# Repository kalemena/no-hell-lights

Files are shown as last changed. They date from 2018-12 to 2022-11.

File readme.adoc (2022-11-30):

= no-hell-lights

*"No Hell"* pronounces like *"Noël"* in French, meaning *"Christmas"* lights.

While this project looks focused on interacting with LED lights, this repository is also a fun way to touch on the below technology:

- Electronic (with very little soldering)
- Arduino IDE coding (C-like) using ESP8266 supporting Wifi
- REST API Designs
- Web-sockets programming
- Web UI - TBD: VueJS UI ?
- Open CV for a little of Machine Learning tools - TBD
- Android - TBD

In short, this repository demonstrate all above topics are "no hell".

== Led Strips

=== Material

* WS2812b comes in 5v or 12v.

[WARNING]
====
12v are hooked 3 by 3, which means that programmatically there are 3 times less leds.
====

Each led consumes 0.2W max, to be safe count 20W for 60 led, that is 20W per meter.

I use 5v 150W power supply so that 10m 600 led strip is fine.

* WS2815 is enhancement of WS2812b (12v with individual address, and with sustain led failure)

* SK6812 is 5v, and has a 4th channel for white light, available in cold or warm white

==== Wiring

Using Arduino Pro Mini 5v as reference.

Wiring for ESP8266 or ESP32 is same as stated below.

As stated in NeoPixel library:

[IMPORTANT]
====
To reduce NeoPixel burnout risk, add 1000 uF capacitor across
pixel power leads, add 300 - 500 Ohm resistor on first pixel's data input
and minimize distance between Arduino and first pixel.  Avoid connecting
on a live circuit...if you must, connect GND first.
====

Then just hook up data pin to one of the pin of arduino.

[NOTE]
====
For 12v strips, make sure not to burn the arduino 5v: don't hook the Vcc !
====

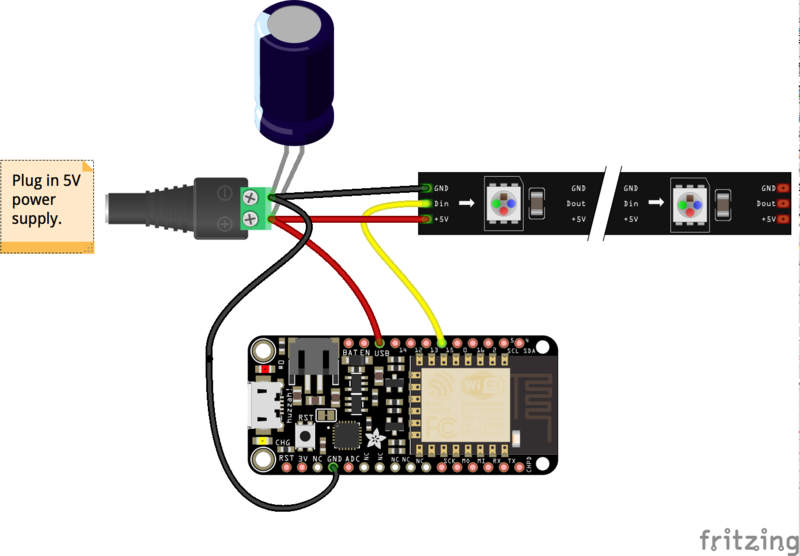
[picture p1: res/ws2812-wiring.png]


=== Board

Details of board can be found under link:boards[]

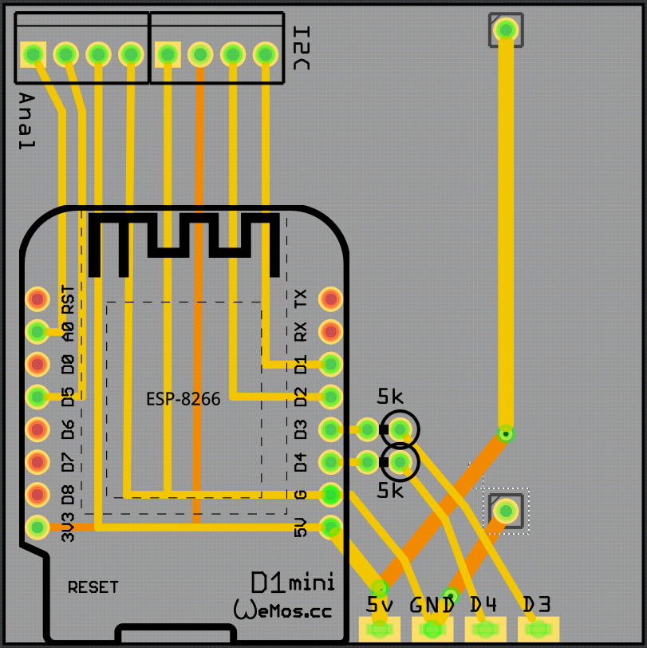
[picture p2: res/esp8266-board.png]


=== Sketches

External samples:

* https://github.com/FastLED/FastLED/blob/master/examples/DemoReel100/DemoReel100.ino[Very Good example]

Internal samples:

* link:sketches/arduino/WS2812/Fast-LED-sample1/Fast-LED-sample1.ino[Fast-LED-sample1.ino]

=== APIs

==== Status

[source,bash]
----
$ curl --request GET http://192.168.1.50/status

{
 "system": {
   "heap": 36944,
   "boot-version": 5,
   "cpu-frequency": 160,
   "sdk": "1.5.3(aec24ac9)",
   "chip-id": 2918146,
   "flash-id": 1458400,
   "flash-size": 4194304,
   "vcc": 65535,
   "gpio": 86053
  },
 "message": "status",
 "properties": {
   "power": 1,
   "animation-mode": "single",
   "brightness": 255,
   "autoplay-duration": 10
  },
 "effects": [
   { "id": 0, "name": "RGB Loop" },
   { "id": 1, "name": "Juggle" },
   { "id": 2, "name": "BPM" },
   { "id": 3, "name": "Sinelon" },
   { "id": 4, "name": "Bouncing Balls" },
   { "id": 5, "name": "Bouncing Balls Multiple" },
   { "id": 6, "name": "Candle" },
   { "id": 7, "name": "Fade-in Fade-out" },
   { "id": 8, "name": "Strobe" },
   { "id": 9, "name": "Halloween Eyes" },
   { "id": 10, "name": "Cylon Bounce" },
   { "id": 11, "name": "New KITT" },
   { "id": 12, "name": "Twinkle" },
   { "id": 13, "name": "Twinkle Random" },
   { "id": 14, "name": "Sparkle" },
   { "id": 15, "name": "Sparkle Snow" },
   { "id": 16, "name": "Running Lights" },
   { "id": 17, "name": "Color Wipe" },
   { "id": 18, "name": "Rainbow Cycle" },
   { "id": 19, "name": "Theater Chase" },
   { "id": 20, "name": "Theater Chase Rainbow" },
   { "id": 21, "name": "Meteor Rain", "selected":true },
   { "id": 22, "name": "Fire" },
   { "id": 23, "name": "Confetti" }
  ]
}
----

==== Settings

Sets some settings.
Can be one of:

* animation-mode= autoplay/single/paint

[source,bash]
----
$ curl --request POST  http://192.168.1.50/settings?animation-mode=single
----

==== Set Pixels

[source,bash]
----
$ curl --request POST --data '{ "pixels": [ { "index":1, "color": 0x123456 }, { "index": 2, "color": 0x987654 } ] }' http://192.168.1.50/pixels/set
{
  "pixels": [
    {
      "index": 1,
      "color": 0x123456
    },
    {
      "index": 2,
      "color": 0x987654
    }
  ]
}
----

==== Reset Pixels

Rest to a given color, for example to white.

[source,bash]
----
$ curl --request POST http://192.168.1.50/pixels/reset?color=0xFFFFFF
----

=== REST Python codes

* link:src/rest-animation-01.py[Sinelon]

* link:src/rest-animation-02.py[Strobe]

* link:src/rest-animation-03.py[Fade-In Fade-Out]

* link:src/rest-animation-04.py[Fade-Out Random Color]

* link:src/rest-animation-05.py[Fading Sinelon]

* link:src/rest-animation-06.py[Twinkle Random]

== Resources

* link:https://arduino-esp8266.readthedocs.io/en/latest/[]
* link:https://github.com/FastLED/FastLED[]
* link:https://github.com/adafruit/Adafruit_NeoPixel[Adafruit_NeoPixel]
* link:https://www.tweaking4all.com/hardware/arduino/adruino-led-strip-effects/[Examples]
* LUSTREON 50CM Aluminum Channel Holder For LED Strip Light Bar Under Cabinet Lamp
* link:https://github.com/hansjny/Natural-Nerd/tree/master/SoundReactive2[]
* link:https://opencv.org/platforms/android/[]

Fun projects:

* link:https://www.instructables.com/id/Wireless-Music-Reactive-Floor-Lamps[Fun project]
* link:https://www.instructables.com/id/Christmas-LED-Sphere/[Fun project]
* link:https://www.instructables.com/id/Super-Simple-RGB-WiFi-Lamp[Fun project]
* Matrix:
** link:https://github.com/AaronLiddiment/LEDMatrix[LED Matrix]
** link:https://github.com/AaronLiddiment/LEDText[LED Text]
** link:https://jorgen-vikinggod.github.io/LEDMatrix/[LEDMatrix]

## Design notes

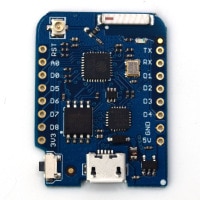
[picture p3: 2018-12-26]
res/wemos-d1.jpeg

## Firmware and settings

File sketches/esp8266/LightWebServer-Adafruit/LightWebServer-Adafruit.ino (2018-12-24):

#include <Adafruit_NeoPixel.h>
#include <ESP8266WiFi.h>
#include <WiFiClient.h>
#include <ESP8266WebServer.h>
#include <ESP8266mDNS.h>
#include <EEPROM.h>
//#include <FS.h>

// ===== CONFIGURATION
#include "settings-wifi.h"

#define LED_PIN D2
#define NUM_LEDS 60
#define LED_BRIGHTNESS 90

#define STATUS_LED 13

#define DEBUG true
#define Serial if(DEBUG)Serial

// ==== STATIC

#define SCENE_THEATER_CHASE_RAINBOW "theaterchaserainbow"

// ===== SETUP
ESP8266WebServer server(80);

// Parameter 1 = number of pixels in strip
// Parameter 2 = Arduino pin number (most are valid)
// Parameter 3 = pixel type flags, add together as needed:
//   NEO_KHZ800  800 KHz bitstream (most NeoPixel products w/WS2812 LEDs)
//   NEO_KHZ400  400 KHz (classic 'v1' (not v2) FLORA pixels, WS2811 drivers)
//   NEO_GRB     Pixels are wired for GRB bitstream (most NeoPixel products)
//   NEO_RGB     Pixels are wired for RGB bitstream (v1 FLORA pixels, not v2)
Adafruit_NeoPixel strip = Adafruit_NeoPixel(NUM_LEDS, LED_PIN, NEO_RGB + NEO_KHZ800);

// IMPORTANT: To reduce NeoPixel burnout risk, add 1000 uF capacitor across
// pixel power leads, add 300 - 500 Ohm resistor on first pixel's data input
// and minimize distance between Arduino and first pixel.  Avoid connecting
// on a live circuit...if you must, connect GND first.

boolean inProgress = false;
byte selectedEffect=0;
boolean effectChanged = false;

void setup(void) {
  Serial.begin(115200);
  
  Serial.println();
  Serial.println("WS2812 initializing");
  strip.setBrightness(LED_BRIGHTNESS);
  strip.begin();
  strip.show(); // Initialize all pixels to 'off'
  delay(50);
  
  pinMode(STATUS_LED, OUTPUT);
  digitalWrite(STATUS_LED, 0);
/*
  Serial.println("SPIFFS initializing");
  SPIFFS.begin();
  {
    Dir dir = SPIFFS.openDir("/");
    while (dir.next()) {    
      String fileName = dir.fileName();
      size_t fileSize = dir.fileSize();
      Serial.printf("FS File: %s, size: %s\n", fileName.c_str(), formatBytes(fileSize).c_str());
    }
    Serial.printf("\n");
  }

  delay(10);
*/ 
  Serial.println("WiFi initializing");
  WiFi.begin(ssid, password);
  Serial.println();
  while(WiFi.status() != WL_CONNECTED) {
    delay(500);
    Serial.print(".");
  }
  Serial.println();
  Serial.print("Connected to ");
  Serial.println(ssid);
  Serial.print("IP address: ");
  Serial.println(WiFi.localIP());
  if(MDNS.begin(host)) {
    Serial.println("MDNS responder started");
  }
  
  Serial.println("Controller initializing");
  server.on("/", handle_Root);
  server.on("/switch", HTTP_GET, handle_SwitchEffect);
  // server.on("/status", handle_Status);
  
  // static files
  //server.serveStatic("/favicon.ico", SPIFFS, "/favicon.ico");
   
  server.onNotFound(handle_NotFound);
  server.begin();
  
  Serial.println("Service initialized");
}

void loop(void) {
  // waiting fo a client
  server.handleClient();

  if(inProgress == false) {
    // record last effect
    EEPROM.get(0,selectedEffect);
    if(selectedEffect>18) { 
      selectedEffect=0;
      EEPROM.put(0,0); 
    }
    
    inProgress = true;
    switch(selectedEffect) {
    
    case 0  : {
                // RGBLoop - no parameters
                RGBLoop();
                break;
              }

    case 1  : {
                // FadeInOut - Color (red, green. blue)
                FadeInOut(0xff, 0x00, 0x00); // red
                FadeInOut(0xff, 0xff, 0xff); // white 
                FadeInOut(0x00, 0x00, 0xff); // blue
                break;
              }
              
    case 2  : {
                // Strobe - Color (red, green, blue), number of flashes, flash speed, end pause
                Strobe(0xff, 0xff, 0xff, 10, 50, 1000);
                break;
              }

    case 3  : {
                // HalloweenEyes - Color (red, green, blue), Size of eye, space between eyes, fade (true/false), steps, fade delay, end pause
                HalloweenEyes(0xff, 0x00, 0x00, 
                              1, 4, 
                              true, random(5,50), random(50,150), 
                              random(1000, 10000));
                HalloweenEyes(0xff, 0x00, 0x00, 
                              1, 4, 
                              true, random(5,50), random(50,150), 
                              random(1000, 10000));
                break;
              }
              
    case 4  : {
                // CylonBounce - Color (red, green, blue), eye size, speed delay, end pause
                CylonBounce(0xff, 0x00, 0x00, 4, 10, 50);
                break;
              }
              
    case 5  : {
                // NewKITT - Color (red, green, blue), eye size, speed delay, end pause
                NewKITT(0xff, 0x00, 0x00, 8, 10, 50);
                break;
              }
              
    case 6  : {
                // Twinkle - Color (red, green, blue), count, speed delay, only one twinkle (true/false) 
                Twinkle(0xff, 0x00, 0x00, 10, 100, false);
                break;
              }
              
    case 7  : { 
                // TwinkleRandom - twinkle count, speed delay, only one (true/false)
                TwinkleRandom(20, 100, false);
                break;
              }
              
    case 8  : {
                // Sparkle - Color (red, green, blue), speed delay
                Sparkle(0xff, 0xff, 0xff, 0);
                break;
              }
               
    case 9  : {
                // SnowSparkle - Color (red, green, blue), sparkle delay, speed delay
                SnowSparkle(0x10, 0x10, 0x10, 20, random(100,1000));
                break;
              }
              
    case 10 : {
                // Running Lights - Color (red, green, blue), wave dealy
                RunningLights(0xff,0x00,0x00, 50);  // red
                RunningLights(0xff,0xff,0xff, 50);  // white
                RunningLights(0x00,0x00,0xff, 50);  // blue
                break;
              }
              
    case 11 : {
                // colorWipe - Color (red, green, blue), speed delay
                colorWipe(0x00,0xff,0x00, 50);
                colorWipe(0x00,0x00,0x00, 50);
                break;
              }

    case 12 : {
                // rainbowCycle - speed delay
                rainbowCycle(20);
                break;
              }

    case 13 : {
                // theatherChase - Color (red, green, blue), speed delay
                theaterChase(0xff,0,0,50);
                break;
              }

    case 14 : {
                // theaterChaseRainbow - Speed delay
                theaterChaseRainbow(50);
                break;
              }

    case 15 : {
                // Fire - Cooling rate, Sparking rate, speed delay
                Fire(55,120,15);
                break;
              }


              // simple bouncingBalls not included, since BouncingColoredBalls can perform this as well as shown below
              // BouncingColoredBalls - Number of balls, color (red, green, blue) array, continuous
              // CAUTION: If set to continuous then this effect will never stop!!! 
              
    case 16 : {
                // mimic BouncingBalls
                byte onecolor[1][3] = { {0xff, 0x00, 0x00} };
                BouncingColoredBalls(1, onecolor, false);
                break;
              }

    case 17 : {
                // multiple colored balls
                byte colors[3][3] = { {0xff, 0x00, 0x00}, 
                                      {0xff, 0xff, 0xff}, 
                                      {0x00, 0x00, 0xff} };
                BouncingColoredBalls(3, colors, false);
                break;
              }

    case 18 : {
                // meteorRain - Color (red, green, blue), meteor size, trail decay, random trail decay (true/false), speed delay 
                meteorRain(0xff,0xff,0xff,10, 64, true, 30);
                break;
              }
    }
    inProgress = false;
  }
}

// ==== Tools

// ==== Controllers

void handle_Root() {
  Serial.println("Client connected");
  digitalWrite(STATUS_LED, 1);
  
  // data from the colorpicker (e.g. #FF00FF)
  // String color = server.arg("c"); Serial.println("Color: " + color);
  // String scene = server.arg("s"); Serial.println("Scene: " + scene);

  // building page
  String result = 
    "<!DOCTYPE HTML> \
     <html>\
      <head>\
       <meta http-equiv=\"Content-type\" content=\"text/html\"; charset=utf-8\">\
       <title>Web relays</title>\
       <link rel=\"stylesheet\" type=\"text/css\" href=\"style.css\">\
      </head>\
      <table>\
       <tr>\
        <th>Description</th>\
        <th>Status</th>\
       </tr>";

  result += "<tr>";
  result += "<td>" + String("Theater Chase Rainbow") + "</td>";
  result += "<td><a href=\"/scene?id=theaterchaserainbow\">Theater Chase Rainbow</button></a></td>";
  result += "</tr>";
  result += "</table>";
  result += "</html>";
  
  server.send(200, "text/html", result);
  digitalWrite(STATUS_LED, 0);
}

void handle_NotFound() {
  digitalWrite(STATUS_LED, 1);
  
  //if(!handleFileRead(server.uri())) {
    String message = "File Not Found\n\n";
    message += "URI: ";
    message += server.uri();
    message += "\nMethod: ";
    message += ( server.method() == HTTP_GET ) ? "GET" : "POST";
    message += "\nArguments: ";
    message += server.args();
    message += "\n";
  
    for ( uint8_t i = 0; i < server.args(); i++ ) {
      message += " " + server.argName ( i ) + ": " + server.arg ( i ) + "\n";
    }
  
    server.send ( 404, "text/plain", message );
  //}
    
  digitalWrite(STATUS_LED, 0);
}

void handle_Status() {  
  String json = "{\n";
  json += " \"heap\":" + String(ESP.getFreeHeap()) + ",\n";
  json += " \"gpio\":"+String((uint32_t)(((GPI | GPO) & 0xFFFF) | ((GP16I & 0x01) << 16))) + ",\n";
  json += "}";
  server.send(200, "application/json", json);
  json = String();
}

void handle_SwitchEffect() {
  selectedEffect++;
  EEPROM.put(0, selectedEffect);
  effectChanged = true;

  String json = "{\n";
  json += " \"effect\":" + String(selectedEffect) + "\n";
  json += "}";
  server.send(200, "application/json", json);
  json = String();
}

// *************************
// ** LEDEffect Functions **
// *************************

void RGBLoop(){
  for(int j = 0; j < 3; j++ ) { 
    // Fade IN
    for(int k = 0; k < 256; k++) { 
      switch(j) { 
        case 0: setAll(k,0,0); break;
        case 1: setAll(0,k,0); break;
        case 2: setAll(0,0,k); break;
      }
      showStrip();
      if(tick()) return;
      delay(3);
    }
    // Fade OUT
    for(int k = 255; k >= 0; k--) { 
      switch(j) { 
        case 0: setAll(k,0,0); break;
        case 1: setAll(0,k,0); break;
        case 2: setAll(0,0,k); break;
      }
      showStrip();
      if(tick()) return;
      delay(3);
    }
  }
}

void FadeInOut(byte red, byte green, byte blue){
  float r, g, b;
      
  for(int k = 0; k < 256; k=k+1) { 
    r = (k/256.0)*red;
    g = (k/256.0)*green;
    b = (k/256.0)*blue;
    setAll(r,g,b);
    showStrip();
    if(tick()) return;
  }
     
  for(int k = 255; k >= 0; k=k-2) {
    r = (k/256.0)*red;
    g = (k/256.0)*green;
    b = (k/256.0)*blue;
    setAll(r,g,b);
    showStrip();
    if(tick()) return;
  }
}

void Strobe(byte red, byte green, byte blue, int StrobeCount, int FlashDelay, int EndPause){
  for(int j = 0; j < StrobeCount; j++) {
    setAll(red,green,blue);
    showStrip();
    if(tick()) return;
    delay(FlashDelay);
    setAll(0,0,0);
    showStrip();
    if(tick()) return;
    delay(FlashDelay);
  }
 
 delay(EndPause);
}

void HalloweenEyes(byte red, byte green, byte blue, 
                   int EyeWidth, int EyeSpace, 
                   boolean Fade, int Steps, int FadeDelay,
                   int EndPause){
  randomSeed(analogRead(0));
  
  int i;
  int StartPoint  = random( 0, NUM_LEDS - (2*EyeWidth) - EyeSpace );
  int Start2ndEye = StartPoint + EyeWidth + EyeSpace;
  
  for(i = 0; i < EyeWidth; i++) {
    setPixel(StartPoint + i, red, green, blue);
    setPixel(Start2ndEye + i, red, green, blue);
  }
  
  showStrip();
  if(tick()) return;
  
  if(Fade==true) {
    float r, g, b;
  
    for(int j = Steps; j >= 0; j--) {
      r = j*(red/Steps);
      g = j*(green/Steps);
      b = j*(blue/Steps);
      
      for(i = 0; i < EyeWidth; i++) {
        setPixel(StartPoint + i, r, g, b);
        setPixel(Start2ndEye + i, r, g, b);
      }
      
      showStrip();
      if(tick()) return;
      delay(FadeDelay);
    }
  }
  
  setAll(0,0,0); // Set all black
  
  delay(EndPause);
}

void CylonBounce(byte red, byte green, byte blue, int EyeSize, int SpeedDelay, int ReturnDelay){

  for(int i = 0; i < NUM_LEDS-EyeSize-2; i++) {
    setAll(0,0,0);
    setPixel(i, red/10, green/10, blue/10);
    for(int j = 1; j <= EyeSize; j++) {
      setPixel(i+j, red, green, blue); 
    }
    setPixel(i+EyeSize+1, red/10, green/10, blue/10);
    showStrip();
    if(tick()) return;
    delay(SpeedDelay);
  }

  delay(ReturnDelay);

  for(int i = NUM_LEDS-EyeSize-2; i > 0; i--) {
    setAll(0,0,0);
    setPixel(i, red/10, green/10, blue/10);
    for(int j = 1; j <= EyeSize; j++) {
      setPixel(i+j, red, green, blue); 
    }
    setPixel(i+EyeSize+1, red/10, green/10, blue/10);
    showStrip();
    if(tick()) return;
    delay(SpeedDelay);
  }
  
  delay(ReturnDelay);
}

void NewKITT(byte red, byte green, byte blue, int EyeSize, int SpeedDelay, int ReturnDelay){
  RightToLeft(red, green, blue, EyeSize, SpeedDelay, ReturnDelay);
  LeftToRight(red, green, blue, EyeSize, SpeedDelay, ReturnDelay);
  OutsideToCenter(red, green, blue, EyeSize, SpeedDelay, ReturnDelay);
  CenterToOutside(red, green, blue, EyeSize, SpeedDelay, ReturnDelay);
  LeftToRight(red, green, blue, EyeSize, SpeedDelay, ReturnDelay);
  RightToLeft(red, green, blue, EyeSize, SpeedDelay, ReturnDelay);
  OutsideToCenter(red, green, blue, EyeSize, SpeedDelay, ReturnDelay);
  CenterToOutside(red, green, blue, EyeSize, SpeedDelay, ReturnDelay);
}

// used by NewKITT
void CenterToOutside(byte red, byte green, byte blue, int EyeSize, int SpeedDelay, int ReturnDelay) {
  for(int i =((NUM_LEDS-EyeSize)/2); i>=0; i--) {
    setAll(0,0,0);
    
    setPixel(i, red/10, green/10, blue/10);
    for(int j = 1; j <= EyeSize; j++) {
      setPixel(i+j, red, green, blue); 
    }
    setPixel(i+EyeSize+1, red/10, green/10, blue/10);
    
    setPixel(NUM_LEDS-i, red/10, green/10, blue/10);
    for(int j = 1; j <= EyeSize; j++) {
      setPixel(NUM_LEDS-i-j, red, green, blue); 
    }
    setPixel(NUM_LEDS-i-EyeSize-1, red/10, green/10, blue/10);
    
    showStrip();
    if(tick()) return;
    delay(SpeedDelay);
  }
  delay(ReturnDelay);
}

// used by NewKITT
void OutsideToCenter(byte red, byte green, byte blue, int EyeSize, int SpeedDelay, int ReturnDelay) {
  for(int i = 0; i<=((NUM_LEDS-EyeSize)/2); i++) {
    setAll(0,0,0);
    
    setPixel(i, red/10, green/10, blue/10);
    for(int j = 1; j <= EyeSize; j++) {
      setPixel(i+j, red, green, blue); 
    }
    setPixel(i+EyeSize+1, red/10, green/10, blue/10);
    
    setPixel(NUM_LEDS-i, red/10, green/10, blue/10);
    for(int j = 1; j <= EyeSize; j++) {
      setPixel(NUM_LEDS-i-j, red, green, blue); 
    }
    setPixel(NUM_LEDS-i-EyeSize-1, red/10, green/10, blue/10);
    
    showStrip();
    if(tick()) return;
    delay(SpeedDelay);
  }
  delay(ReturnDelay);
}

// used by NewKITT
void LeftToRight(byte red, byte green, byte blue, int EyeSize, int SpeedDelay, int ReturnDelay) {
  for(int i = 0; i < NUM_LEDS-EyeSize-2; i++) {
    setAll(0,0,0);
    setPixel(i, red/10, green/10, blue/10);
    for(int j = 1; j <= EyeSize; j++) {
      setPixel(i+j, red, green, blue); 
    }
    setPixel(i+EyeSize+1, red/10, green/10, blue/10);
    showStrip();
    if(tick()) return;
    delay(SpeedDelay);
  }
  delay(ReturnDelay);
}

// used by NewKITT
void RightToLeft(byte red, byte green, byte blue, int EyeSize, int SpeedDelay, int ReturnDelay) {
  for(int i = NUM_LEDS-EyeSize-2; i > 0; i--) {
    setAll(0,0,0);
    setPixel(i, red/10, green/10, blue/10);
    for(int j = 1; j <= EyeSize; j++) {
      setPixel(i+j, red, green, blue); 
    }
    setPixel(i+EyeSize+1, red/10, green/10, blue/10);
    showStrip();
    if(tick()) return;
    delay(SpeedDelay);
  }
  delay(ReturnDelay);
}

void Twinkle(byte red, byte green, byte blue, int Count, int SpeedDelay, boolean OnlyOne) {
  setAll(0,0,0);
  
  for (int i=0; i<Count; i++) {
     setPixel(random(NUM_LEDS),red,green,blue);
     showStrip();
     if(tick()) return;
     delay(SpeedDelay);
     if(OnlyOne) { 
       setAll(0,0,0); 
     }
   }
  
  delay(SpeedDelay);
}

void TwinkleRandom(int Count, int SpeedDelay, boolean OnlyOne) {
  setAll(0,0,0);
  
  for (int i=0; i<Count; i++) {
     setPixel(random(NUM_LEDS),random(0,255),random(0,255),random(0,255));
     showStrip();
     if(tick()) return;
     delay(SpeedDelay);
     if(OnlyOne) { 
       setAll(0,0,0); 
     }
   }
  
  delay(SpeedDelay);
}

void Sparkle(byte red, byte green, byte blue, int SpeedDelay) {
  int Pixel = random(NUM_LEDS);
  setPixel(Pixel,red,green,blue);
  showStrip();
  if(tick()) return;
  delay(SpeedDelay);
  setPixel(Pixel,0,0,0);
}

void SnowSparkle(byte red, byte green, byte blue, int SparkleDelay, int SpeedDelay) {
  setAll(red,green,blue);
  
  int Pixel = random(NUM_LEDS);
  setPixel(Pixel,0xff,0xff,0xff);
  showStrip();
  if(tick()) return;
  delay(SparkleDelay);
  setPixel(Pixel,red,green,blue);
  showStrip();
  if(tick()) return;
  delay(SpeedDelay);
}

void RunningLights(byte red, byte green, byte blue, int WaveDelay) {
  int Position=0;
  
  for(int i=0; i<NUM_LEDS*2; i++)
  {
      Position++; // = 0; //Position + Rate;
      for(int i=0; i<NUM_LEDS; i++) {
        // sine wave, 3 offset waves make a rainbow!
        //float level = sin(i+Position) * 127 + 128;
        //setPixel(i,level,0,0);
        //float level = sin(i+Position) * 127 + 128;
        setPixel(i,((sin(i+Position) * 127 + 128)/255)*red,
                   ((sin(i+Position) * 127 + 128)/255)*green,
                   ((sin(i+Position) * 127 + 128)/255)*blue);
      }
      
      showStrip();
      if(tick()) return;
      delay(WaveDelay);
  }
}

void colorWipe(byte red, byte green, byte blue, int SpeedDelay) {
  for(uint16_t i=0; i<NUM_LEDS; i++) {
      setPixel(i, red, green, blue);
      showStrip();
      if(tick()) return;
      delay(SpeedDelay);
  }
}

void rainbowCycle(int SpeedDelay) {
  byte *c;
  uint16_t i, j;

  for(j=0; j<256*5; j++) { // 5 cycles of all colors on wheel
    for(i=0; i< NUM_LEDS; i++) {
      c=Wheel(((i * 256 / NUM_LEDS) + j) & 255);
      setPixel(i, *c, *(c+1), *(c+2));
    }
    showStrip();
    if(tick()) return;
    delay(SpeedDelay);
  }
}

// used by rainbowCycle and theaterChaseRainbow
byte * Wheel(byte WheelPos) {
  static byte c[3];
  
  if(WheelPos < 85) {
   c[0]=WheelPos * 3;
   c[1]=255 - WheelPos * 3;
   c[2]=0;
  } else if(WheelPos < 170) {
   WheelPos -= 85;
   c[0]=255 - WheelPos * 3;
   c[1]=0;
   c[2]=WheelPos * 3;
  } else {
   WheelPos -= 170;
   c[0]=0;
   c[1]=WheelPos * 3;
   c[2]=255 - WheelPos * 3;
  }

  return c;
}

void theaterChase(byte red, byte green, byte blue, int SpeedDelay) {
  for (int j=0; j<10; j++) {  //do 10 cycles of chasing
    for (int q=0; q < 3; q++) {
      for (int i=0; i < NUM_LEDS; i=i+3) {
        setPixel(i+q, red, green, blue);    //turn every third pixel on
      }
      showStrip();
      if(tick()) return;
     
      delay(SpeedDelay);
     
      for (int i=0; i < NUM_LEDS; i=i+3) {
        setPixel(i+q, 0,0,0);        //turn every third pixel off
      }
    }
  }
}

void theaterChaseRainbow(int SpeedDelay) {
  byte *c;
  
  for (int j=0; j < 256; j++) {     // cycle all 256 colors in the wheel
    for (int q=0; q < 3; q++) {
        for (int i=0; i < NUM_LEDS; i=i+3) {
          c = Wheel( (i+j) % 255);
          setPixel(i+q, *c, *(c+1), *(c+2));    //turn every third pixel on
        }
        showStrip();
        if(tick()) return;
       
        delay(SpeedDelay);
       
        for (int i=0; i < NUM_LEDS; i=i+3) {
          setPixel(i+q, 0,0,0);        //turn every third pixel off
        }
    }
  }
}

void Fire(int Cooling, int Sparking, int SpeedDelay) {
  static byte heat[NUM_LEDS];
  int cooldown;
  
  // Step 1.  Cool down every cell a little
  for( int i = 0; i < NUM_LEDS; i++) {
    cooldown = random(0, ((Cooling * 10) / NUM_LEDS) + 2);
    
    if(cooldown>heat[i]) {
      heat[i]=0;
    } else {
      heat[i]=heat[i]-cooldown;
    }
  }
  
  // Step 2.  Heat from each cell drifts 'up' and diffuses a little
  for( int k= NUM_LEDS - 1; k >= 2; k--) {
    heat[k] = (heat[k - 1] + heat[k - 2] + heat[k - 2]) / 3;
  }
    
  // Step 3.  Randomly ignite new 'sparks' near the bottom
  if( random(255) < Sparking ) {
    int y = random(7);
    heat[y] = heat[y] + random(160,255);
    //heat[y] = random(160,255);
  }

  // Step 4.  Convert heat to LED colors
  for( int j = 0; j < NUM_LEDS; j++) {
    setPixelHeatColor(j, heat[j] );
  }

  showStrip();
  if(tick()) return;
  delay(SpeedDelay);
}

void setPixelHeatColor (int Pixel, byte temperature) {
  // Scale 'heat' down from 0-255 to 0-191
  byte t192 = round((temperature/255.0)*191);
 
  // calculate ramp up from
  byte heatramp = t192 & 0x3F; // 0..63
  heatramp <<= 2; // scale up to 0..252
 
  // figure out which third of the spectrum we're in:
  if( t192 > 0x80) {                     // hottest
    setPixel(Pixel, 255, 255, heatramp);
  } else if( t192 > 0x40 ) {             // middle
    setPixel(Pixel, 255, heatramp, 0);
  } else {                               // coolest
    setPixel(Pixel, heatramp, 0, 0);
  }
}
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

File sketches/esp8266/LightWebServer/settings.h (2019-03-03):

#include "settings-wifi.h"

#define LED_PIN         D2
#define NUM_LEDS        150
#define MILLI_AMPS      2000 // IMPORTANT: set the max milli-Amps of your power supply (4A = 4000mA)
#define STATUS_LED      13

#define SETTING_POWER_NAME                  "power"
#define SETTING_POWER_VALUE_ON              "on"
#define SETTING_POWER_VALUE_OFF             "off"
#define SETTING_POWER 0
boolean settingsPowerOn = true;

#define SETTING_AUTOPLAY_DURATION_NAME      "autoplay_duration"
#define SETTING_AUTOPLAY_DURATION 1
uint8_t settingsAutoplayDuration = 10;

#define SETTING_BRIGHTNESS_NAME             "brightness"
#define SETTING_BRIGHTNESS 2
uint8_t settingsBrightness = 100;

#define SETTING_EFFECT_NAME                 "effect"
#define SETTING_WANTED_EFFECT_INDEX 3
uint8_t settingsWantedEffectIndex = 0;

#define SETTING_ANIMATION_MODE_NAME         "animation_mode"
#define SETTING_ANIMATION_MODE 4
#define SETTING_ANIMATION_MODE_AUTOPLAY 0
#define SETTING_ANIMATION_MODE_SINGLE   1
#define SETTING_ANIMATION_MODE_PAINT    2
uint8_t settingsAnimationMode = SETTING_ANIMATION_MODE_AUTOPLAY;

// Reading JSON values
uint8_t readAnimiationMode(String valueString) {
  Serial.println("Read: animation-mode=" + valueString);
  uint8_t valueAM = SETTING_ANIMATION_MODE_AUTOPLAY;
  if(valueString == "single" || valueString == String(SETTING_ANIMATION_MODE_SINGLE)) {
    valueAM = SETTING_ANIMATION_MODE_SINGLE;
  } else if(valueString == "paint" || valueString == String(SETTING_ANIMATION_MODE_PAINT)) {
    valueAM = SETTING_ANIMATION_MODE_PAINT;
  } else if(valueString == "autoplay" || valueString == String(SETTING_ANIMATION_MODE_AUTOPLAY)) {
    valueAM = SETTING_ANIMATION_MODE_AUTOPLAY;
  } else {
    Serial.println("Read: animation-mode=error");
  }
  return valueAM;
}

// Rendering String value
String renderAnimiationMode(uint8_t valueAM) {
  Serial.println("Render: animation-mode=" + String(valueAM));
  String valueString = "autoplay";
  if(valueAM == SETTING_ANIMATION_MODE_SINGLE) {
    valueString = "single";
  } else if(valueAM == SETTING_ANIMATION_MODE_PAINT) {
    valueString = "paint";
  } else if(valueAM == SETTING_ANIMATION_MODE_AUTOPLAY) {
    valueString = "autoplay";
  } else {
    Serial.println("Render: animation-mode=error");
  }
  return valueString;
}

// Manage EEPROM
void loadSettings() {
  EEPROM.begin(512);
  settingsPowerOn = EEPROM.read(SETTING_POWER);  
  Serial.println("  PowerOn = " + String(settingsPowerOn));
  
  settingsAutoplayDuration = EEPROM.read(SETTING_AUTOPLAY_DURATION);  
  Serial.println("  PlayDuration = " + String(settingsAutoplayDuration) );
  
  settingsBrightness = EEPROM.read(SETTING_BRIGHTNESS);  
  Serial.println("  Brightness = " + String(settingsBrightness) );
  
  settingsAnimationMode = readAnimiationMode(String(EEPROM.read(SETTING_ANIMATION_MODE)));
  Serial.println("  Animation Mode = " + String(settingsAnimationMode) );
  
  settingsWantedEffectIndex = EEPROM.read(SETTING_WANTED_EFFECT_INDEX);
  Serial.println("  Wanted Effect Index = " + String(settingsWantedEffectIndex) );
}

void saveEEPROM(int idx, uint8_t value) {
  //EEPROM.put(0, value);
  EEPROM.write(idx, value);
  EEPROM.commit();
}

extern void setBrightness(uint8_t value);
extern const uint8_t effectDetailsCount;
// extern void changeEffect();
void saveSetting(String optionName, String optionValue) {
  if(optionName.equals(SETTING_POWER_NAME)) {
    settingsPowerOn = optionValue.equals(SETTING_POWER_VALUE_ON);
    saveEEPROM(SETTING_POWER, settingsPowerOn);
    
  } else if(optionName.equals(SETTING_AUTOPLAY_DURATION_NAME)) {
    settingsAutoplayDuration = optionValue.toInt();
    saveEEPROM(SETTING_AUTOPLAY_DURATION, settingsAutoplayDuration);
    
  } else if(optionName.equals(SETTING_BRIGHTNESS_NAME)) {
    setBrightness(optionValue.toInt());
    saveEEPROM(SETTING_BRIGHTNESS, optionValue.toInt());
    
  } else if(optionName.equals(SETTING_EFFECT_NAME)) {
    settingsWantedEffectIndex = optionValue.toInt() % effectDetailsCount;
    saveEEPROM(SETTING_WANTED_EFFECT_INDEX, settingsWantedEffectIndex);
    
  } else if(optionName.equals(SETTING_ANIMATION_MODE_NAME)) {
    settingsAnimationMode = readAnimiationMode(optionValue);
    saveEEPROM(SETTING_ANIMATION_MODE, settingsAnimationMode);
    // changeEffect();
    
  } else {
    Serial.println("Unknown settings: " + optionName + "=" + String(optionValue));
  }
}

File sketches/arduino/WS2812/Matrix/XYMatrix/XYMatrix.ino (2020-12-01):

#include <FastLED.h>

#define LED_PIN  8

#define COLOR_ORDER GRB
#define CHIPSET     WS2811

#define BRIGHTNESS 32

// Helper functions for an two-dimensional XY matrix of pixels.
// Simple 2-D demo code is included as well.
//
//     XY(x,y) takes x and y coordinates and returns an LED index number,
//             for use like this:  leds[ XY(x,y) ] == CRGB::Red;
//             No error checking is performed on the ranges of x and y.
//
//     XYsafe(x,y) takes x and y coordinates and returns an LED index number,
//             for use like this:  leds[ XY(x,y) ] == CRGB::Red;
//             Error checking IS performed on the ranges of x and y, and an
//             index of "-1" is returned.  Special instructions below
//             explain how to use this without having to do your own error
//             checking every time you use this function.  
//             This is a slightly more advanced technique, and 
//             it REQUIRES SPECIAL ADDITIONAL setup, described below.


// Params for width and height
const uint8_t kMatrixWidth = 50;
const uint8_t kMatrixHeight = 10;

// Param for different pixel layouts
const bool    kMatrixSerpentineLayout = true;
// Set 'kMatrixSerpentineLayout' to false if your pixels are 
// laid out all running the same way, like this:
//
//     0 >  1 >  2 >  3 >  4
//                         |
//     .----<----<----<----'
//     |
//     5 >  6 >  7 >  8 >  9
//                         |
//     .----<----<----<----'
//     |
//    10 > 11 > 12 > 13 > 14
//                         |
//     .----<----<----<----'
//     |
//    15 > 16 > 17 > 18 > 19
//
// Set 'kMatrixSerpentineLayout' to true if your pixels are 
// laid out back-and-forth, like this:
//
//     0 >  1 >  2 >  3 >  4
//                         |
//                         |
//     9 <  8 <  7 <  6 <  5
//     |
//     |
//    10 > 11 > 12 > 13 > 14
//                        |
//                        |
//    19 < 18 < 17 < 16 < 15
//
// Bonus vocabulary word: anything that goes one way 
// in one row, and then backwards in the next row, and so on
// is call "boustrophedon", meaning "as the ox plows."


// This function will return the right 'led index number' for 
// a given set of X and Y coordinates on your matrix.  
// IT DOES NOT CHECK THE COORDINATE BOUNDARIES.  
// That's up to you.  Don't pass it bogus values.
//
// Use the "XY" function like this:
//
//    for( uint8_t x = 0; x < kMatrixWidth; x++) {
//      for( uint8_t y = 0; y < kMatrixHeight; y++) {
//      
//        // Here's the x, y to 'led index' in action: 
//        leds[ XY( x, y) ] = CHSV( random8(), 255, 255);
//      
//      }
//    }
//
//
uint16_t XY( uint8_t x, uint8_t y)
{
  uint16_t i;
  
  if( kMatrixSerpentineLayout == false) {
    i = (y * kMatrixWidth) + x;
  }

  if( kMatrixSerpentineLayout == true) {
    if( y & 0x01) {
      // Odd rows run backwards
      uint8_t reverseX = (kMatrixWidth - 1) - x;
      i = (y * kMatrixWidth) + reverseX;
    } else {
      // Even rows run forwards
      i = (y * kMatrixWidth) + x;
    }
  }
  
  return i;
}


// Once you've gotten the basics working (AND NOT UNTIL THEN!)
// here's a helpful technique that can be tricky to set up, but 
// then helps you avoid the needs for sprinkling array-bound-checking
// throughout your code.
//
// It requires a careful attention to get it set up correctly, but
// can potentially make your code smaller and faster.
//
// Suppose you have an 8 x 5 matrix of 40 LEDs.  Normally, you'd
// delcare your leds array like this:
//    CRGB leds[40];
// But instead of that, declare an LED buffer with one extra pixel in
// it, "leds_plus_safety_pixel".  Then declare "leds" as a pointer to
// that array, but starting with the 2nd element (id=1) of that array: 
//    CRGB leds_with_safety_pixel[41];
//    CRGB* const leds( leds_plus_safety_pixel + 1);
// Then you use the "leds" array as you normally would.
// Now "leds[0..N]" are aliases for "leds_plus_safety_pixel[1..(N+1)]",
// AND leds[-1] is now a legitimate and safe alias for leds_plus_safety_pixel[0].
// leds_plus_safety_pixel[0] aka leds[-1] is now your "safety pixel".
//
// Now instead of using the XY function above, use the one below, "XYsafe".
//
// If the X and Y values are 'in bounds', this function will return an index
// into the visible led array, same as "XY" does.
// HOWEVER -- and this is the trick -- if the X or Y values
// are out of bounds, this function will return an index of -1.
// And since leds[-1] is actually just an alias for leds_plus_safety_pixel[0],
// it's a totally safe and legal place to access.  And since the 'safety pixel'
// falls 'outside' the visible part of the LED array, anything you write 
// there is hidden from view automatically.
// Thus, this line of code is totally safe, regardless of the actual size of
// your matrix:
//    leds[ XYsafe( random8(), random8() ) ] = CHSV( random8(), 255, 255);
//
// The only catch here is that while this makes it safe to read from and
// write to 'any pixel', there's really only ONE 'safety pixel'.  No matter
// what out-of-bounds coordinates you write to, you'll really be writing to
// that one safety pixel.  And if you try to READ from the safety pixel,
// you'll read whatever was written there last, reglardless of what coordinates
// were supplied.

#define NUM_LEDS (kMatrixWidth * kMatrixHeight)
CRGB leds_plus_safety_pixel[ NUM_LEDS + 1];
CRGB* const leds( leds_plus_safety_pixel + 1);

uint16_t XYsafe( uint8_t x, uint8_t y)
{
  if( x >= kMatrixWidth) return -1;
  if( y >= kMatrixHeight) return -1;
  return XY(x,y);
}


// Demo that USES "XY" follows code below
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

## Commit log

2018-12-17 Add FastLED sample
2018-12-22 Add ESP8266 wiring
2018-12-29 Fix autoplay memory leak
    [LightWebServer.ino, effects.h]
2018-12-31 Add settings (not working yet)
    [LightWebServer.ino, settings.h]
2019-02-03 Add reset mode color parameter
    [LightWebServer.ino, effects.h]
2019-02-03 Add samples python
2019-02-05 Fix properties read - avoid infinite reboot
    [LightWebServer.ino]
2019-02-09 Add sample wifi settings
2019-03-03 testing 150 leds
2019-03-05 Add ESP8266 simple board
    [no-hell-lights-wemos-pcb.fzz]
2019-03-06 Add board sample
2019-03-07 Update board
    [no-hell-lights-wemos-pcb.fzz]
2019-12-15 Add first ESP32 examples
2020-12-01 Add sample text matrix
